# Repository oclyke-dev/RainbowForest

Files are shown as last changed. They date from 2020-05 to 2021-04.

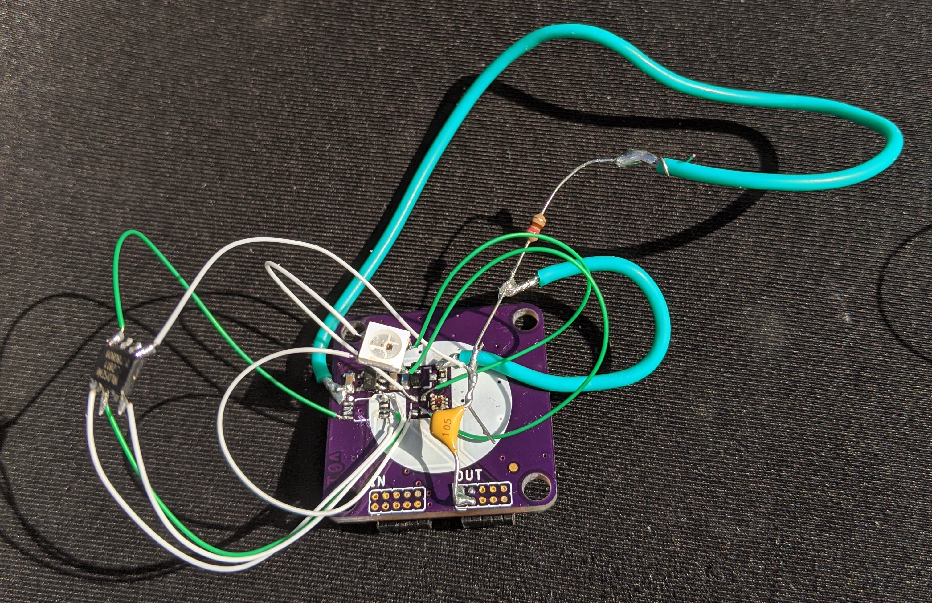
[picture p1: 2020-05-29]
process_documentation/v01_testing/Prototype v01_edited.jpg

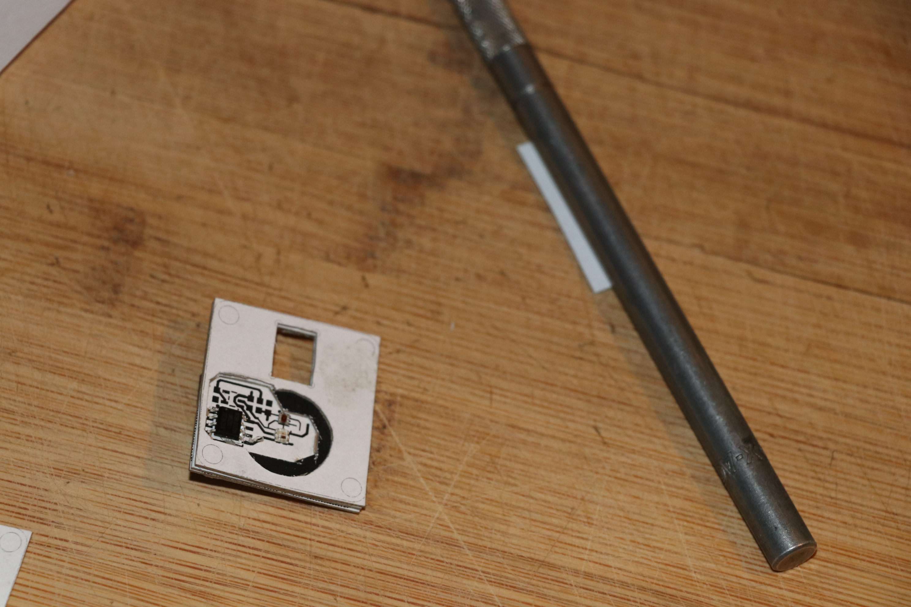
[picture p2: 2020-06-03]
process_documentation/IMG_0715.JPG

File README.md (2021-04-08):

# Rainbow Forest

Rainbow Forest is an interactive experience to compose short songs on a larger-than-life musical staff. Designed for the Museum of Boulder's 2020 Plazeum 2.0 exhibit this installation engages creativity and interaction through the combination of sounds and sights.

## Firmware

There are several microcontrollers working in concert (pun intended) to make the Rainbow Forest function. They are:

- **conductor** : the main processor conducting audio operations and the overall system operation
- **network hub** : the network hub handles communication between the column controllers and the conductor 
- **column controllers** : each column of notes on the staff is managed by an individual controller

The programs that run on each of these devices can be found in ```firmware/main```

Components that are common between programs can be found in ```firmware/components```. These components are expected to be symbolically linked into the main program directories. Arduino requires additional source code to be placed within a ```src``` directory. From the repository root directory one may run the link scripts to quickly make symbolic links from every component to every main program. 

- **linux**: ```./scripts/link.sh```
- **windows**: ```scripts\link.bat```

You may also create the symbolic links manually (Linux / Windows examples follow).

- **linux**: ```ln -s firmware/components/${component} firmware/main/${program}/src/components```
- **windows**: ```mklink /J firmware\main\%program%\src\components\%component% firmware\components\%component%```

Partial / experimental programs may be contained in ```firmware/prototyping``` for reference

## Hardware

The hardware directory contains the Eagle design files and Gerber manufacturing files for the original Rainbow Forest installation.

## Web

The Rainbow Forest installation connects to the world wide web, allowing users to check in on its status from anywhere.

In the museum a single-board computer running Chromium is used as a dedicated user interface.

```
./Chromium.app/Contents/MacOS/Chromium --app=https://oclyke.dev/rainbow-forest
```

## raspberry pi
the rainbow forest uses a local raspberry pi microcomputer to provide a user interface for museum visitors. this is acheived by using Chromium in kiosk mode. the raspberry pi also translates ```ws://``` messages into ```wss://``` messages for transfer to the main server (since the esp32s were unhappy running ```wss://```) 

[headless raspberry pi configuration](https://desertbot.io/blog/headless-raspberry-pi-3-bplus-ssh-wifi-setup)
[configuring rapberry pi for kiosk mode](https://die-antwort.eu/techblog/2017-12-setup-raspberry-pi-for-kiosk-mode/)
[using systemd on the pi](https://www.raspberrypi.org/documentation/linux/usage/systemd.md)
[using node and pm2 to daemonize applications](https://dev.to/bogdaaamn/run-your-nodejs-application-on-a-headless-raspberry-pi-4jnn)
[distributions of node for raspberry pi](https://github.com/nodesource/distributions)

## License

This project is subject to the license listed in file ```LICENSE.md```

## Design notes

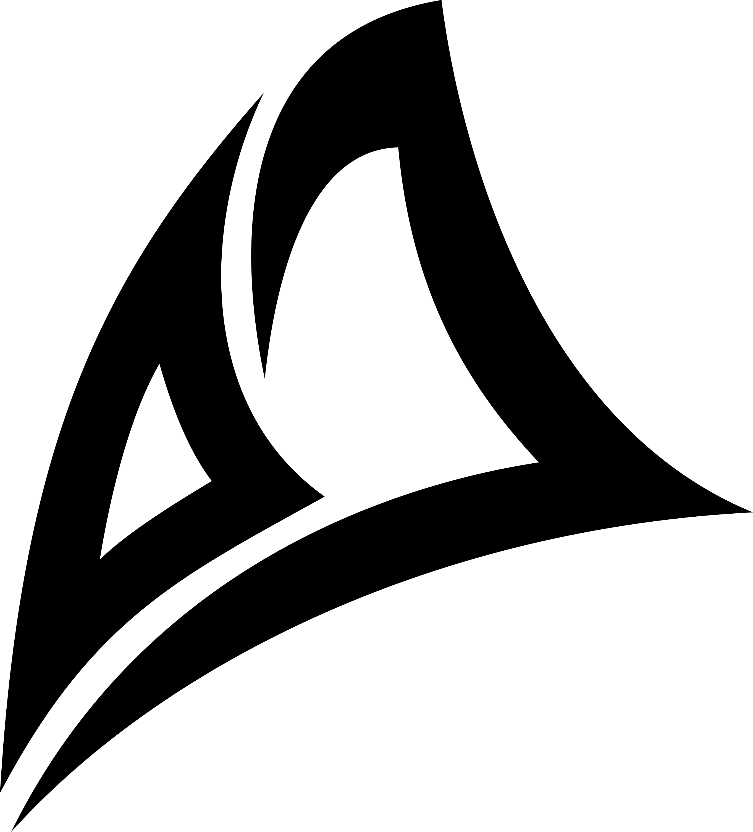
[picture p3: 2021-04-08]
web/client/src/assets/ocl_L.PNG

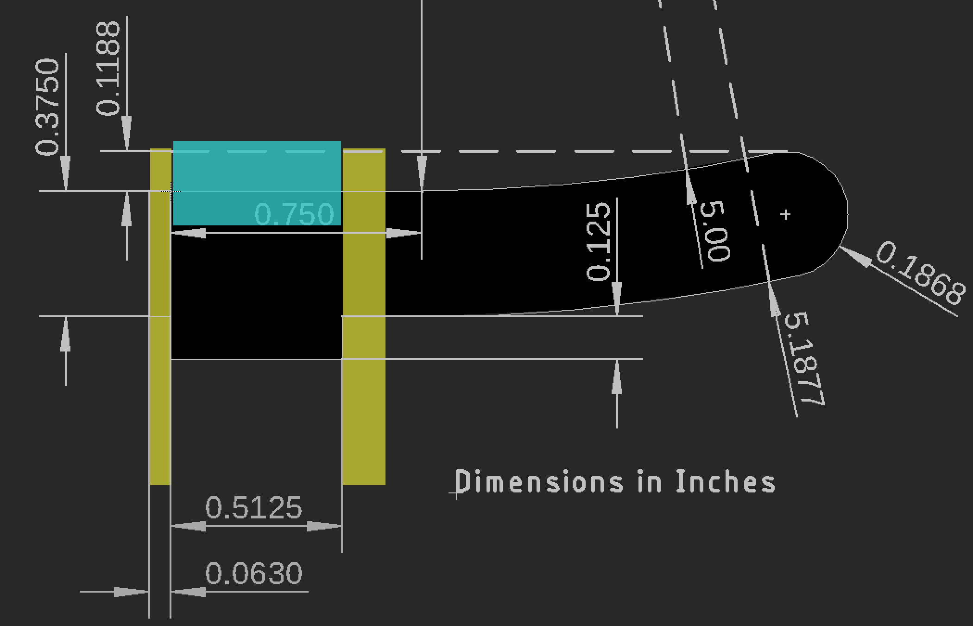
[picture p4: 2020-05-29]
process_documentation/Screen Shot 2020-04-22 at 11.09.29 PM.png

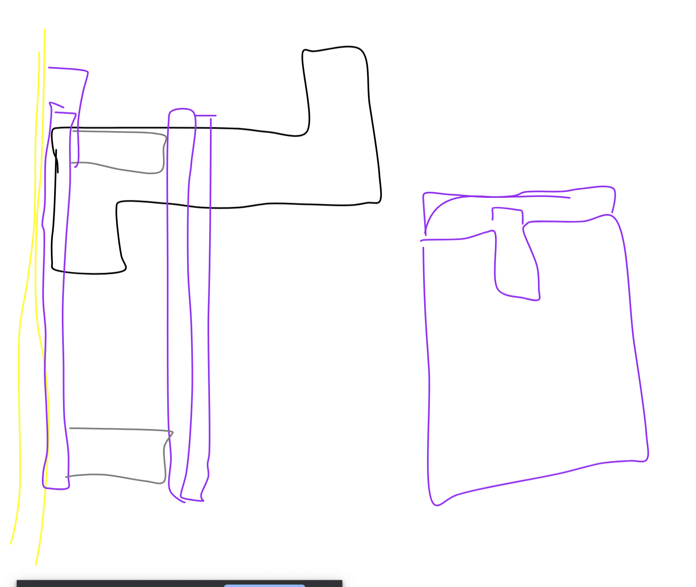
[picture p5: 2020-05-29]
process_documentation/Screen Shot 2020-04-22 at 2.52.55 PM.png

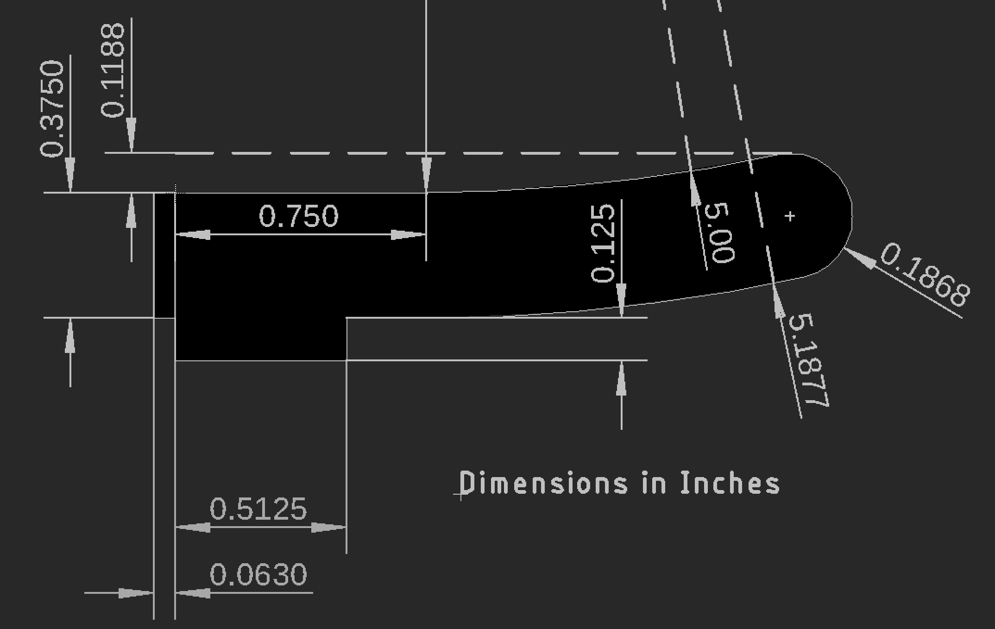
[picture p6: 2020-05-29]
process_documentation/Screen Shot 2020-04-22 at 11.09.07 PM.png

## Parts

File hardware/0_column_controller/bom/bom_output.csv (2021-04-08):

Qty | PROD_ID | Names | Value | Package
4 | CAP-00810 | C1; C2; C10; C11 | 0.1uF | 0603
5 | CAP-13930 | C3; C4; C7; C8; C9 | 1.0uF | 0603
2 | CAP-14106 | C5; C6 | 4.7uF | 0603
5 | DIO-08575 | D1; D5; D6; D7; D8 |  | LED-0603
2 | DIO-14072 | D2; D3 | 3A/10V/280mV | SOD-323
1 | DIO-00819 | D4 |  | LED-0603
1 | CONN-14485 | J1 |  | SCREWTERMINAL-3.5MM-4
1 | CONN-14122 | J3 |  | USB-C-16P
1 | CONN-14503 | J4 | JTAG | 2X5-SMD-1.27MM
1 | TRANS-13337 | Q1 |  | SC70-6
3 | RES-00824 | R1; R5; R6 | 10k | 0603
9 | RES-07856 | R2; R3; R4; R8; R9; R12; R13; R14; R15 | 1k | 0603
1 | RES-12581 | R7 | 10 | 0603
2 | RES-12083 | R10; R11 | 5.1k | 0603
2 | SWCH-13065 | S1; S2 |  | TACTILE_SWITCH_SMD_4.6X2.8MM
1 |  | U1 | ESP-WROVER-32ESP-WROVER-32 | ESP-WROVER-32
1 | VREG-12457 | U2 | 3.3V | SOT23-5
1 | IC-14020 | U3 | CP2102N | QFN24

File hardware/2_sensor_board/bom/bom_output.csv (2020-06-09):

Qty | PROD_ID | Names | Value | Package
3 | CAP-00868 | C1; C2; C3 | 1.0uF | 0603
1 |  | D1 | WS2812B | WS2812-2020
2 | CONN-14503 | J1; J2 | JTAG | 2X5-SMD-1.27MM
1 | RES-07861 | R2 | 220 | 0603
1 | IC-12055 | U1 | ISL29125 | ODFN-6
1 | VREG-12457 | U2 | 3.3V | SOT23-5
1 |  | U3 | WS2811 | SOIC-8

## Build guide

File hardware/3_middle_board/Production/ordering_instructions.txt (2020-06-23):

panel size, 99x100mm
PCB thickness, 1.6mm
number of layers, 2
soldermask color, Unknown
silkscreen color, White
oz copper, 1oz
finish, HASL lead free
stencils, bottom
pcs per panel, 9
min trace width, 10.0000mm / 0.3937in
min drill size, 1.2700mm / 0.0500in

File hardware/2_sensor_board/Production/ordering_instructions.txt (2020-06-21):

panel size, 99x100mm
PCB thickness, 1.6mm
number of layers, 2
soldermask color, Unknown
silkscreen color, White
oz copper, 1oz
finish, HASL lead free
stencils, top+bottom
pcs per panel, 9
min trace width, 0.2032mm / 0.0080in
min drill size, 0.3810mm / 0.0150in

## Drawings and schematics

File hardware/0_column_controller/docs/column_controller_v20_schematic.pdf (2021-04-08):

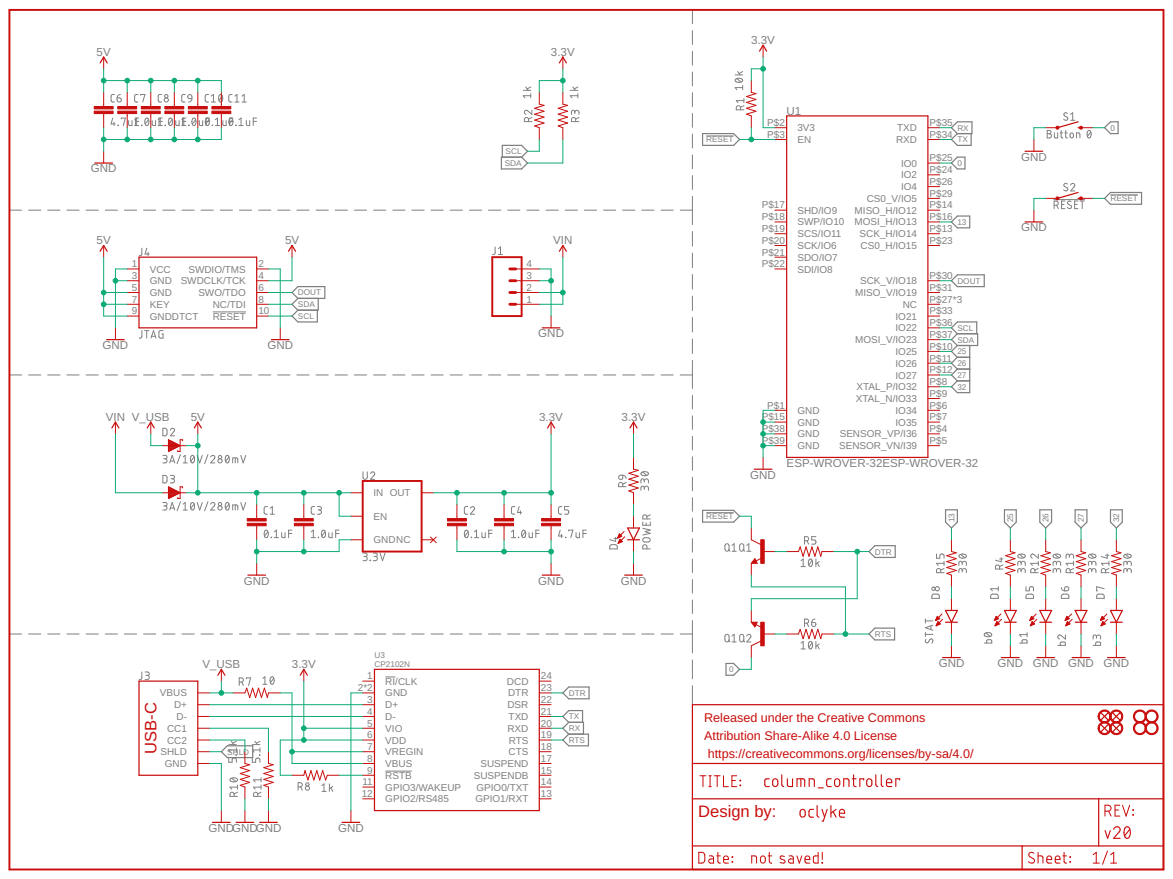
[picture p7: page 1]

Released under the Creative Commons Attribution Share-Alike 4.0 License

https://creativecommons.org/licenses/by-sa/4.0/

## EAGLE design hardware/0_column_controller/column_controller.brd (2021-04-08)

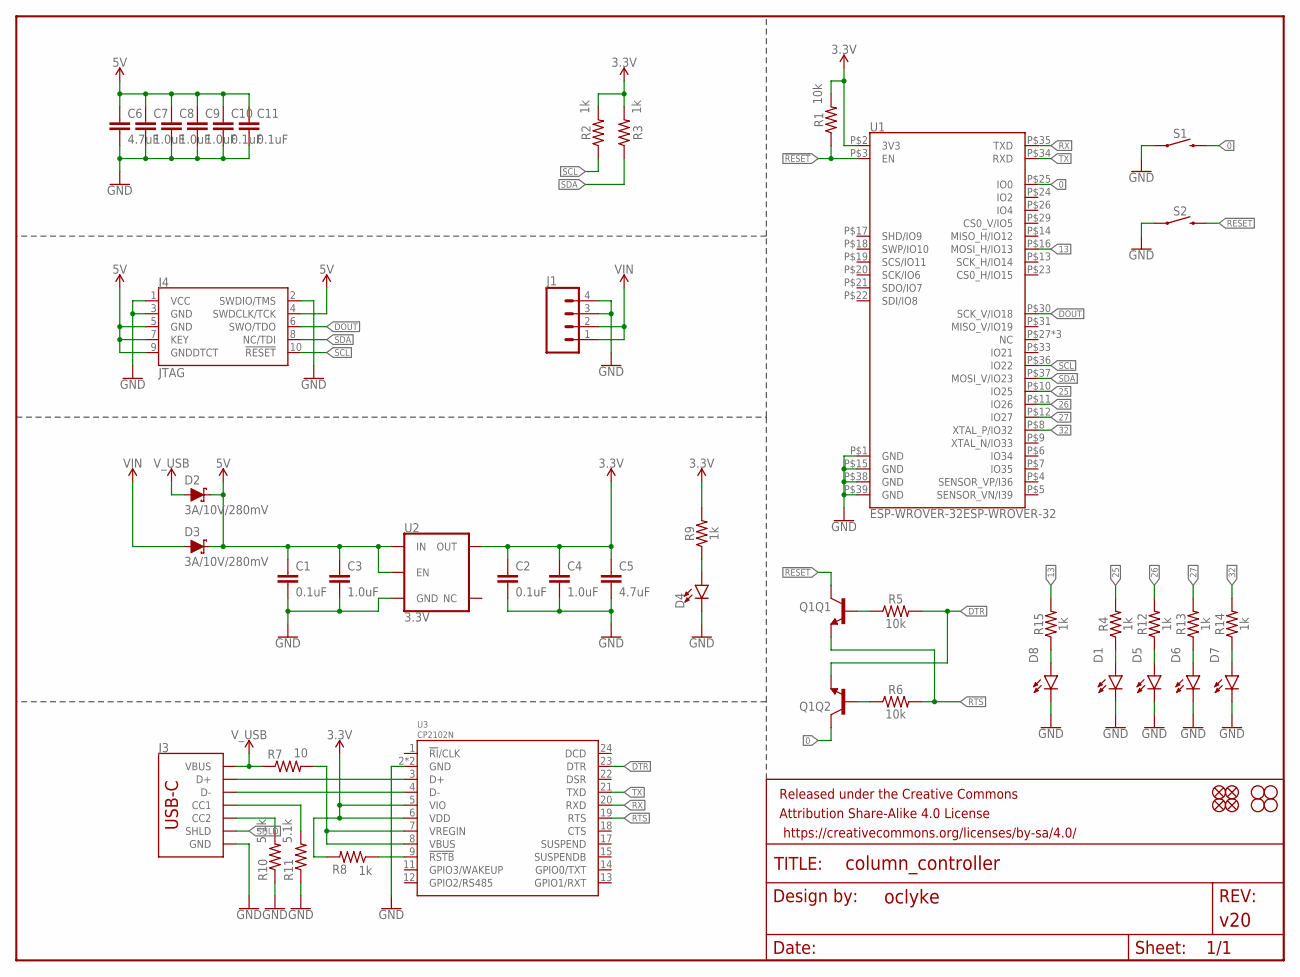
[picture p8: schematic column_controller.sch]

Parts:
C1, C2, C10, C11: 0.1uF; 0603
C3, C4, C7, C8, C9: 1.0uF; 0603
C5, C6: 4.7uF; 0603
D1, D5, D6, D7, D8: LED-BLUE0603; LED-0603
D2, D3: 3A/10V/280mV; SOD-323
D4: LED-RED0603; LED-0603
FD1, FD2, FD3, FD4: FIDUCIAL1X2; FIDUCIAL-1X2
FRAME1: FRAME-LETTER; CREATIVE_COMMONS
H1, H2, H3, H4: STAND-OFF#8; STAND-OFF-#8
J1: CONN_04SCREW; SCREWTERMINAL-3.5MM-4
J3: USB_C_2-LAYER; USB-C-16P
J4: JTAG; 2X5-SMD-1.27MM
Q1: TRANS_NPN_DUAL-MBT3904DW1T1; SC70-6
R1, R5, R6: 10k; 0603
R2, R3, R4, R8, R9, R12, R13, R14, R15: 1k; 0603
R7: 10; 0603
R10, R11: 5.1k; 0603
S1, S2: MOMENTARY-SWITCH-SPST-SMD-4.6X2.8MM; TACTILE_SWITCH_SMD_4.6X2.8MM
U1: ESP-WROVER-32ESP-WROVER-32; ESP-WROVER-32
U2: 3.3V; SOT23-5
U3: CP2102N; QFN24

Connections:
0: Q1.6 (C), S1.3 (2), S1.4 (2), U1.P$25 (IO0)
3.3V: C2.1, C4.1, C5.1, R1.2, R2.2, R3.2, R8.2, R9.2, U1.P$2 (3V3), U2.5 (OUT), U3.5 (VIO), U3.6 (VDD)
5V: C1.1, C3.1, C6.1, C7.1, C8.1, C9.1, C10.1, C11.1, D2.C, D3.C, J4.4 (SWDCLK/TCK), J4.5 (GND), J4.7 (KEY), J4.9 (GNDDTCT), U2.1 (IN), U2.3 (EN)
13: R15.2, U1.P$16 (MOSI_H/IO13)
25: R4.2, U1.P$10 (IO25)
26: R12.2, U1.P$11 (IO26)
27: R13.2, U1.P$12 (IO27)
32: R14.2, U1.P$8 (XTAL_P/IO32)
!RESET: Q1.3 (C), R1.1, S2.3 (2), S2.4 (2), U1.P$3 (EN)
DOUT: J4.6 (SWO/TDO), U1.P$30 (SCK_V/IO18)
DTR: Q1.1 (E), R5.2, U3.23 (DTR)
GND: C1.2, C2.2, C3.2, C4.2, C5.2, C6.2, C7.2, C8.2, C9.2, C10.2, C11.2, D1.C, D4.C, D5.C, D6.C, D7.C, D8.C, J1.3, J1.4, J3.GND, J3.GND2 (GND), J4.1 (VCC), J4.2 (SWDIO/TMS), J4.3 (GND), R10.1, R11.1, S1.1, S1.2 (1), S2.1, S2.2 (1), U1.P$1 (GND), U1.P$15 (GND), U1.P$38 (GND), U1.P$39 (GND), U2.2 (GND), U3.2 (GND), U3.PAD (GND)
unnamed: J3.A7 (D-), J3.B7 (D-), U3.4 (D-)
unnamed: J3.A6 (D+), J3.B6 (D+), U3.3 (D+)
unnamed: Q1.2 (B), R6.1
unnamed: D1.A, R4.1
unnamed: Q1.5 (B), R5.1
unnamed: R7.2, U3.7 (VREGIN), U3.8 (VBUS)
unnamed: R8.1, U3.9 (!RSTB)
unnamed: D4.A, R9.1
unnamed: D5.A, R12.1
unnamed: J3.A5 (CC1), R11.2
unnamed: J3.B5 (CC2), R10.2
unnamed: D6.A, R13.1
unnamed: D7.A, R14.1
unnamed: D8.A, R15.1
RTS: Q1.4 (E), R6.2, U3.19 (RTS)
RX: U1.P$35 (TXD), U3.20 (RXD)
SCL: J4.10 (!RESET), R2.1, U1.P$36 (IO22)
SDA: J4.8 (NC/TDI), R3.1, U1.P$37 (MOSI_V/IO23)
SHLD: J3.SHLD1 (SHLD), J3.SHLD2 (SHLD), J3.SHLD3 (SHLD), J3.SHLD4 (SHLD), J3.SHLD5 (SHLD), J3.SHLD6 (SHLD), J3.SHLD7 (SHLD), J3.SHLD8 (SHLD)
TX: U1.P$34 (RXD), U3.21 (TXD)
VIN: D3.A, J1.1, J1.2
V_USB: D2.A, J3.VBUS1 (VBUS), J3.VBUS2 (VBUS), R7.1

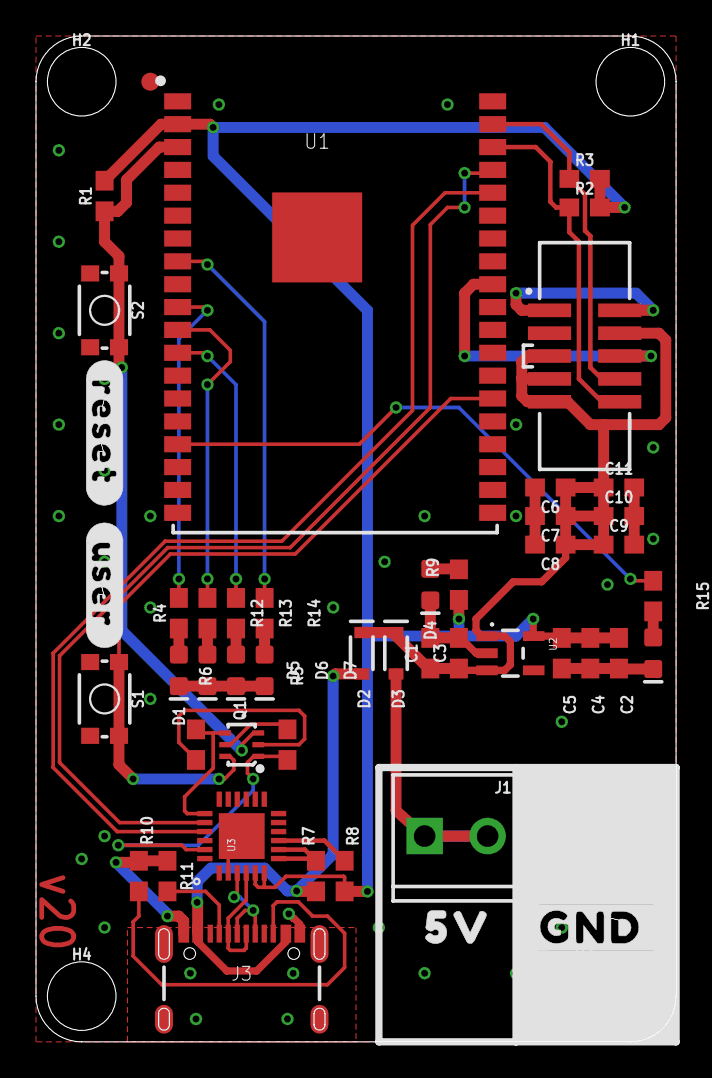
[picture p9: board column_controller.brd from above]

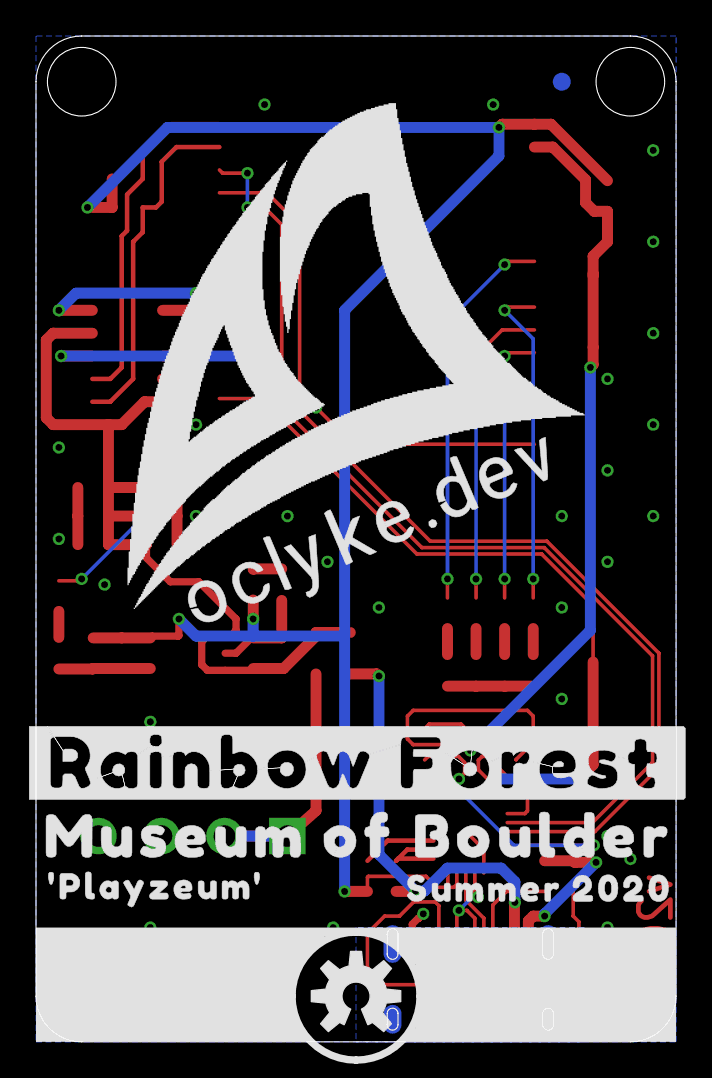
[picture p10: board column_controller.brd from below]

Board: 2 copper layers, 35.5 x 55.9 mm, 63 parts (9 on the bottom side), 34 nets.

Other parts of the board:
U$1: 5V2
U$2: #GND#6
U$4: #USER#2
U$5: #RESET#3
U$6: OCL_L#PNG
U$7: MUSEUM_OF_BOULDER9
U$8: OCLYKE#DEV7
U$9: #RAINBOW_FOREST#8
U$10: SUMMER_202010
U$11: #PLAYZEUM#10
U$12: OSHW-LOGO-M

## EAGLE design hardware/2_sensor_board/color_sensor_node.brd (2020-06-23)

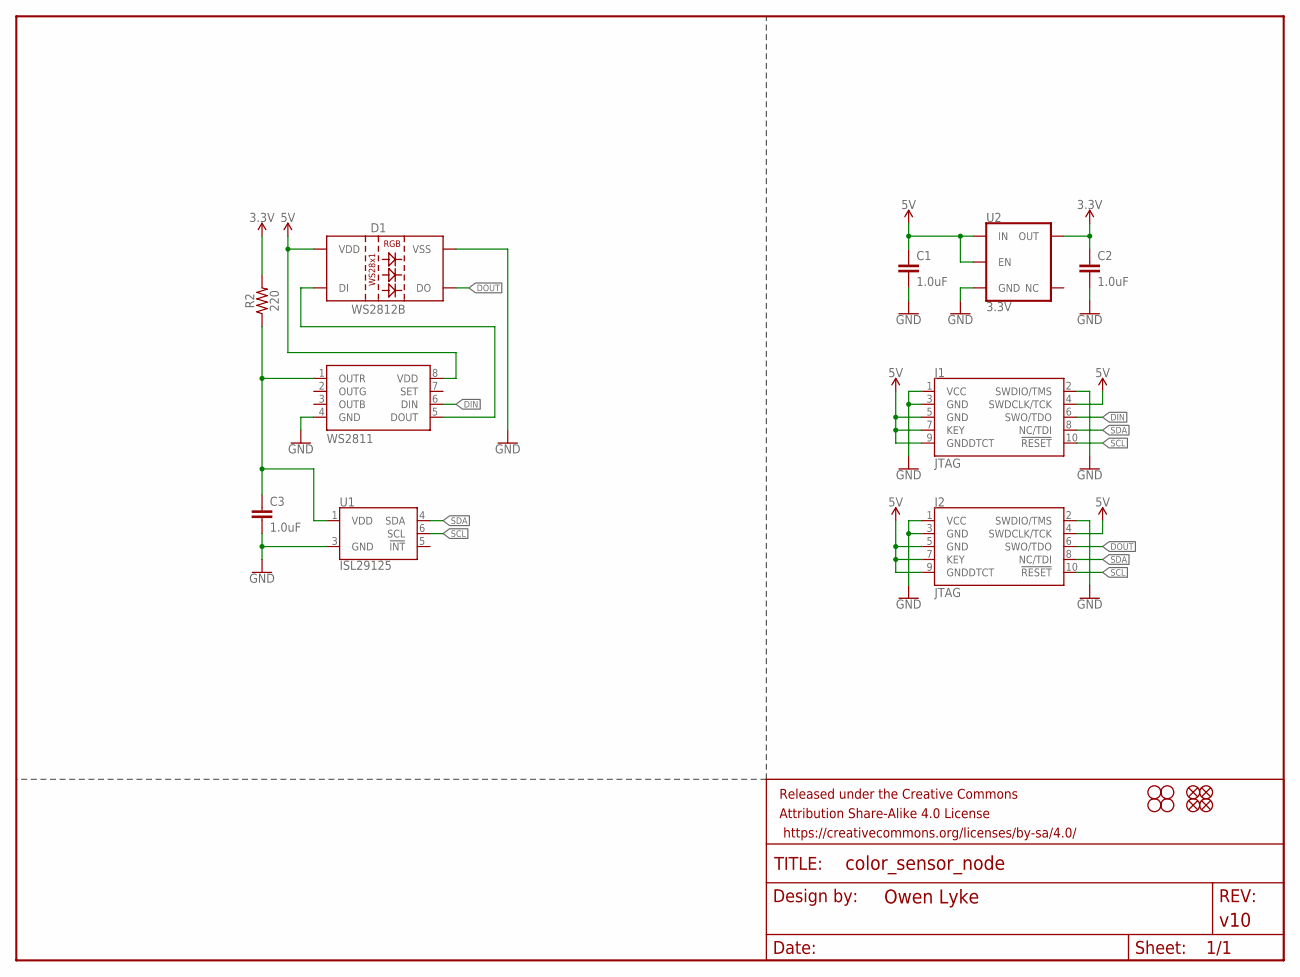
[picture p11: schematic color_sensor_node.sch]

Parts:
C1, C2, C3: 1.0uF; 0603
D1: WS2812B; WS2812-2020
FD1, FD2, FD3, FD4: FIDUCIAL1X2; FIDUCIAL-1X2
FRAME1: FRAME-LETTER; CREATIVE_COMMONS
H1, H2, H3, H4: STAND-OFF#8; STAND-OFF-#8
J1, J2: JTAG; 2X5-SMD-1.27MM
R2: 220; 0603
U1: ISL29125; ODFN-6
U2: 3.3V; SOT23-5
U3: WS2811; SOIC-8

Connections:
3.3V: C2.1, R2.2, U2.5 (OUT)
5V: C1.1, D1.4 (VDD), J1.4 (SWDCLK/TCK), J1.5 (GND), J1.7 (KEY), J1.9 (GNDDTCT), J2.4 (SWDCLK/TCK), J2.5 (GND), J2.7 (KEY), J2.9 (GNDDTCT), U2.1 (IN), U2.3 (EN), U3.8 (VDD)
DIN: J1.6 (SWO/TDO), U3.6 (DIN)
DOUT: D1.1 (DO), J2.6 (SWO/TDO)
GND: C1.2, C2.2, C3.2, D1.2 (VSS), J1.1 (VCC), J1.2 (SWDIO/TMS), J1.3 (GND), J2.1 (VCC), J2.2 (SWDIO/TMS), J2.3 (GND), U1.3 (GND), U2.2 (GND), U3.4 (GND)
unnamed: C3.1, R2.1, U1.1 (VDD), U3.1 (OUTR)
unnamed: D1.3 (DI), U3.5 (DOUT)
SCL: J1.10 (!RESET), J2.10 (!RESET), U1.6 (SCL)
SDA: J1.8 (NC/TDI), J2.8 (NC/TDI), U1.4 (SDA)

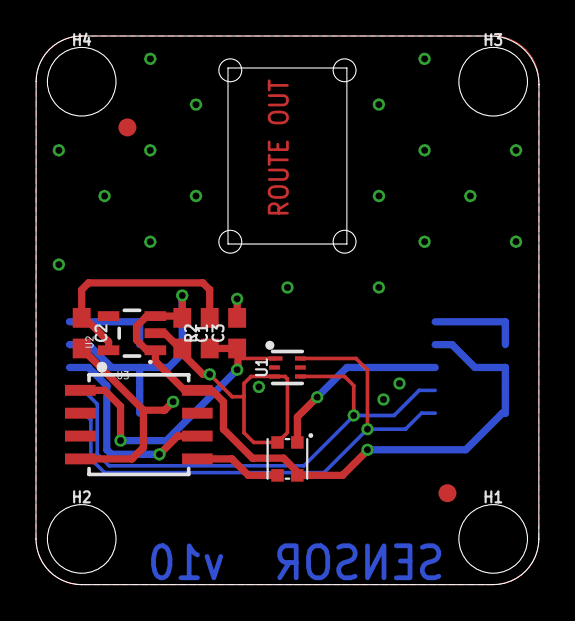
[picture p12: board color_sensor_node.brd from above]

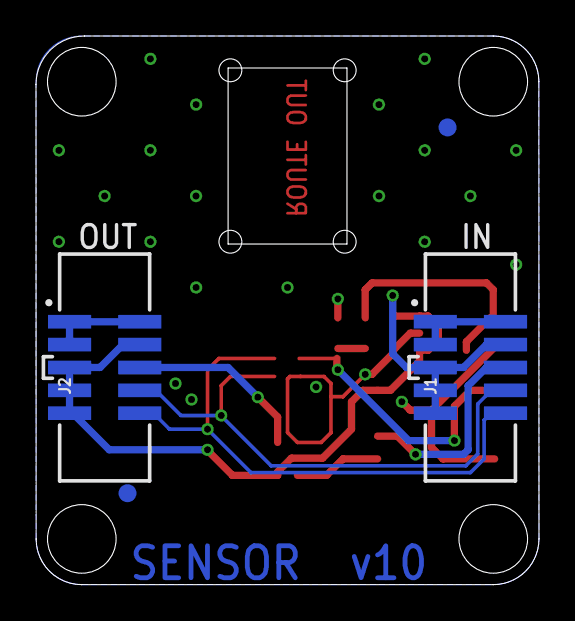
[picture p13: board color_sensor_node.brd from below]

Board: 2 copper layers, 27.9 x 30.5 mm, 19 parts (4 on the bottom side), 9 nets.

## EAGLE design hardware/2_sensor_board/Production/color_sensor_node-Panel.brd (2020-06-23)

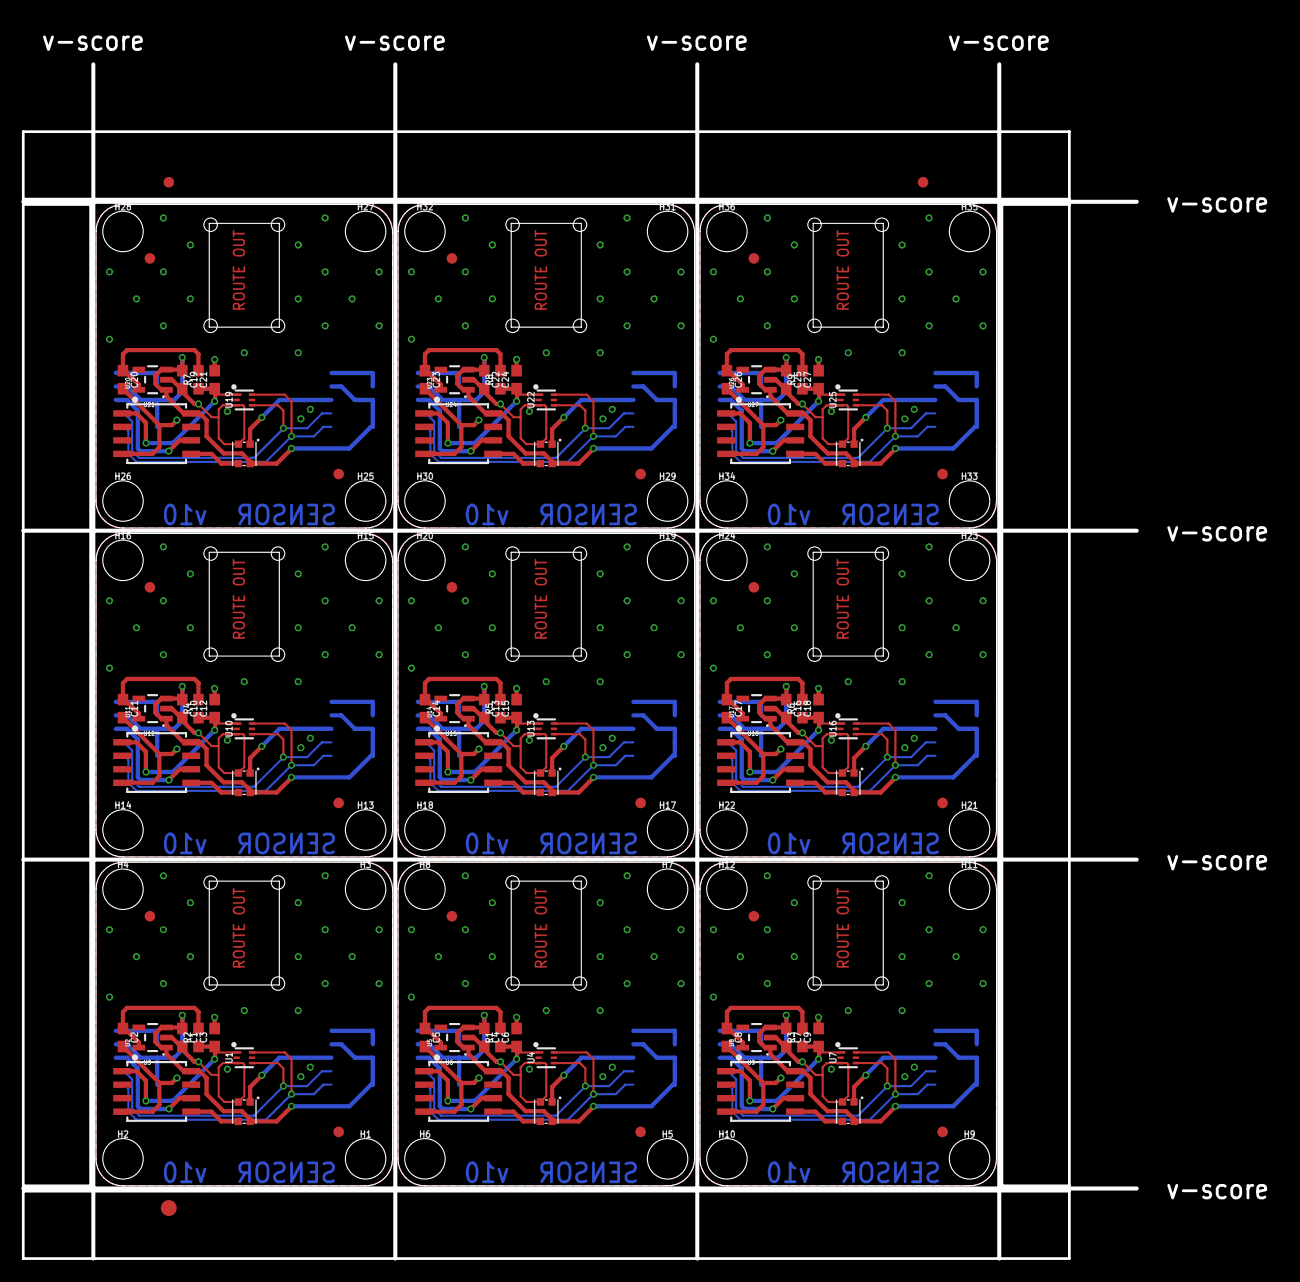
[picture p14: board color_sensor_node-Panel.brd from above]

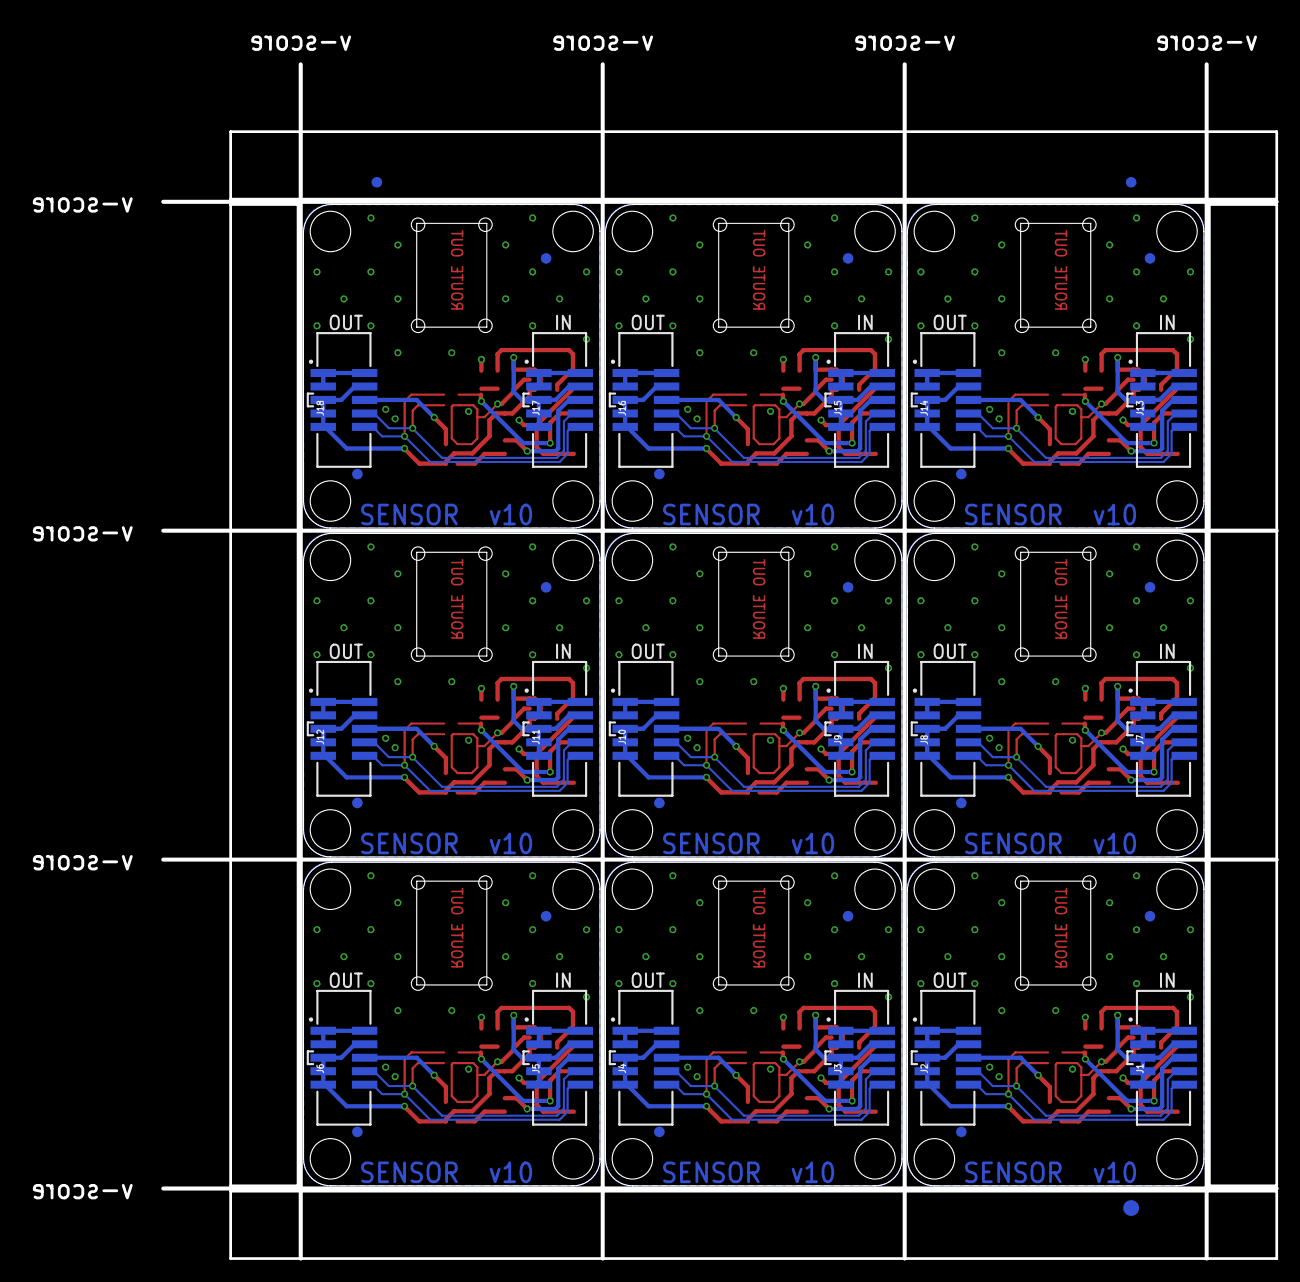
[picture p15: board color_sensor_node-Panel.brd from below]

Board: 2 copper layers, 104.9 x 112.5 mm, 168 parts (39 on the bottom side), 81 nets.

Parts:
C1, C2, C3, C4, C5, C6, C7, C8, C9, C10, C11, C12, C13, C14, C15, C16, C17, C18, C19, C20, C21, C22, C23, C24, C25, C26, C27: 1.0uF; 0603
D1, D2, D3, D4, D5, D6, D7, D8, D9: WS2812B; WS2812-2020
E$1, E$2, E$3, E$4: FIDUCIAL-1X2
E$5, E$6: FIDUCIAL-1.5X3
FD1, FD2, FD3, FD4, FD5, FD6, FD7, FD8, FD9, FD10, FD11, FD12, FD13, FD14, FD15, FD16, FD17, FD18, FD19, FD20, FD21, FD22, FD23, FD24, FD25, FD26, FD27, FD28, FD29, FD30, FD31, FD32, FD33, FD34, FD35, FD36: FIDUCIAL1X2; FIDUCIAL-1X2
H1, H2, H3, H4, H5, H6, H7, H8, H9, H10, H11, H12, H13, H14, H15, H16, H17, H18, H19, H20, H21, H22, H23, H24, H25, H26, H27, H28, H29, H30, H31, H32, H33, H34, H35, H36: STAND-OFF#8; STAND-OFF-#8
J1, J2, J3, J4, J5, J6, J7, J8, J9, J10, J11, J12, J13, J14, J15, J16, J17, J18: JTAG; 2X5-SMD-1.27MM
R1, R2, R3, R4, R5, R6, R7, R8, R9: 220; 0603
U1, U4, U7, U10, U13, U16, U19, U22, U25: ISL29125; ODFN-6
U2, U5, U8, U11, U14, U17, U20, U23, U26: 3.3V; SOT23-5
U3, U6, U9, U12, U15, U18, U21, U24, U27: WS2811; SOIC-8

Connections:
3.3V: C2.1, R2.2, U2.5
3.3V1: C5.1, R1.2, U5.5
3.3V2: C8.1, R3.2, U8.5
3.3V3: C11.1, R4.2, U11.5
3.3V4: C14.1, R5.2, U14.5
3.3V5: C17.1, R6.2, U17.5
3.3V6: C20.1, R7.2, U20.5
3.3V7: C23.1, R8.2, U23.5
3.3V8: C26.1, R9.2, U26.5
5V: C1.1, D1.4, J1.4, J1.5, J1.7, J1.9, J2.4, J2.5, J2.7, J2.9, U2.1, U2.3, U3.8
5V1: C4.1, D2.4, J3.4, J3.5, J3.7, J3.9, J4.4, J4.5, J4.7, J4.9, U5.1, U5.3, U6.8
5V2: C7.1, D3.4, J5.4, J5.5, J5.7, J5.9, J6.4, J6.5, J6.7, J6.9, U8.1, U8.3, U9.8
5V3: C10.1, D4.4, J7.4, J7.5, J7.7, J7.9, J8.4, J8.5, J8.7, J8.9, U11.1, U11.3, U12.8
5V4: C13.1, D5.4, J9.4, J9.5, J9.7, J9.9, J10.4, J10.5, J10.7, J10.9, U14.1, U14.3, U15.8
5V5: C16.1, D6.4, J11.4, J11.5, J11.7, J11.9, J12.4, J12.5, J12.7, J12.9, U17.1, U17.3, U18.8
5V6: C19.1, D7.4, J13.4, J13.5, J13.7, J13.9, J14.4, J14.5, J14.7, J14.9, U20.1, U20.3, U21.8
5V7: C22.1, D8.4, J15.4, J15.5, J15.7, J15.9, J16.4, J16.5, J16.7, J16.9, U23.1, U23.3, U24.8
5V8: C25.1, D9.4, J17.4, J17.5, J17.7, J17.9, J18.4, J18.5, J18.7, J18.9, U26.1, U26.3, U27.8
DIN: J1.6, U3.6
DIN1: J3.6, U6.6
DIN2: J5.6, U9.6
DIN3: J7.6, U12.6
DIN4: J9.6, U15.6
DIN5: J11.6, U18.6
DIN6: J13.6, U21.6
DIN7: J15.6, U24.6
DIN8: J17.6, U27.6
DOUT: D1.1, J2.6
DOUT1: D2.1, J4.6
DOUT2: D3.1, J6.6
DOUT3: D4.1, J8.6
DOUT4: D5.1, J10.6
DOUT5: D6.1, J12.6
DOUT6: D7.1, J14.6
DOUT7: D8.1, J16.6
DOUT8: D9.1, J18.6
GND: C1.2, C2.2, C3.2, D1.2, J1.1, J1.2, J1.3, J2.1, J2.2, J2.3, U1.3, U2.2, U3.4
GND1: C4.2, C5.2, C6.2, D2.2, J3.1, J3.2, J3.3, J4.1, J4.2, J4.3, U4.3, U5.2, U6.4
GND2: C7.2, C8.2, C9.2, D3.2, J5.1, J5.2, J5.3, J6.1, J6.2, J6.3, U7.3, U8.2, U9.4
GND3: C10.2, C11.2, C12.2, D4.2, J7.1, J7.2, J7.3, J8.1, J8.2, J8.3, U10.3, U11.2, U12.4
GND4: C13.2, C14.2, C15.2, D5.2, J9.1, J9.2, J9.3, J10.1, J10.2, J10.3, U13.3, U14.2, U15.4
GND5: C16.2, C17.2, C18.2, D6.2, J11.1, J11.2, J11.3, J12.1, J12.2, J12.3, U16.3, U17.2, U18.4
GND6: C19.2, C20.2, C21.2, D7.2, J13.1, J13.2, J13.3, J14.1, J14.2, J14.3, U19.3, U20.2, U21.4
GND7: C22.2, C23.2, C24.2, D8.2, J15.1, J15.2, J15.3, J16.1, J16.2, J16.3, U22.3, U23.2, U24.4
GND8: C25.2, C26.2, C27.2, D9.2, J17.1, J17.2, J17.3, J18.1, J18.2, J18.3, U25.3, U26.2, U27.4
unnamed: D2.3, U6.5
unnamed: C3.1, R2.1, U1.1, U3.1
unnamed: C6.1, R1.1, U4.1, U6.1
unnamed: D1.3, U3.5
unnamed: D3.3, U9.5
unnamed: C9.1, R3.1, U7.1, U9.1
unnamed: D4.3, U12.5
unnamed: C12.1, R4.1, U10.1, U12.1
unnamed: D5.3, U15.5
unnamed: C15.1, R5.1, U13.1, U15.1
unnamed: D6.3, U18.5
unnamed: C18.1, R6.1, U16.1, U18.1
unnamed: D7.3, U21.5
unnamed: C21.1, R7.1, U19.1, U21.1
unnamed: D8.3, U24.5
unnamed: C24.1, R8.1, U22.1, U24.1
unnamed: D9.3, U27.5
unnamed: C27.1, R9.1, U25.1, U27.1
SCL: J1.10, J2.10, U1.6
SCL1: J3.10, J4.10, U4.6
SCL2: J5.10, J6.10, U7.6
SCL3: J7.10, J8.10, U10.6
SCL4: J9.10, J10.10, U13.6
SCL5: J11.10, J12.10, U16.6
SCL6: J13.10, J14.10, U19.6
SCL7: J15.10, J16.10, U22.6
SCL8: J17.10, J18.10, U25.6
SDA: J1.8, J2.8, U1.4
SDA1: J3.8, J4.8, U4.4
SDA2: J5.8, J6.8, U7.4
SDA3: J7.8, J8.8, U10.4
SDA4: J9.8, J10.8, U13.4
SDA5: J11.8, J12.8, U16.4
SDA6: J13.8, J14.8, U19.4
SDA7: J15.8, J16.8, U22.4
SDA8: J17.8, J18.8, U25.4

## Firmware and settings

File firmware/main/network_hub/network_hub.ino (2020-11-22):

/* 
// This file is subject to the terms and conditions defined in
// file 'LICENSE.md', which is part of this source code package.
*/

// BOARD: SparkFun SAMD21 Mini Breakout

#include "src/components/configuration/configuration.h"
#include "src/components/uart_bridge/uart_bridge.h"
#include "src/components/staff/staff.h"
#include "src/components/cart/cart.h"
#include "src/components/cat/cat.h"
#include "src/components/cmt/cmt.h"

#include <Wire.h>
#include "wiring_private.h" // pinPeripheral() function

#define LED0 A0
#define LED1 A3
#define LED2 8
#define LED3 9

#define BUTTON0 10
#define BUTTON1 12

#define RAND_PIN A1

#define DEBUG_PORT SerialUSB
#define DEBUG_BAUD (115200)

#define BRIDGE_PORT Serial1
#define BRIDGE_BAUD (115200)
UARTBridge <cart_t> cartBridge(BRIDGE_PORT);
UARTBridge <cat_t> catBridge(BRIDGE_PORT);
cart_t cart;
cat_t cat;
Staff <staff_data_t> staff;

#define NETWORK_SDA_PIN 11
#define NETWORK_SCL_PIN 13
#define NETWORK_WIRE_IT_HANDLER SERCOM1_Handler
TwoWire NetworkWire(&sercom1, NETWORK_SDA_PIN, NETWORK_SCL_PIN);
#define NETWORK_ADDRESS_BY_COL(c) (c + 0x04)

volatile bool cat_received = false;
volatile bool cleanup_cat_received = false;
volatile bool full_update_requested = true;
bool full_update_sent = false;

volatile bool button0 = false;
void button0ISR() {
  button0 = true;
}

volatile bool button1 = false;
void button1ISR() {
  button0 = true;
}

void onCatReception(cat_t* cat, void* args){
  cat_received = true;

  if(cat->col >= STAFF_COLS){
    DEBUG_PORT.println("received an invalid cat");
    return;
  }

  size_t node_data_size = (sizeof(column_map_t)/sizeof(uint8_t)); // note: if node_data_size * STAFF_ROWS > 32 you will need to use separate transmissions!
  uint8_t r = ((cat->rH) << 4) | ((cat->rL) & 0x0F);              // reconstructed red component of color
  uint8_t g = ((cat->gH) << 4) | ((cat->gL) & 0x0F);              // reconstructed green component of color
  uint8_t b = ((cat->bH) << 4) | ((cat->bL) & 0x0F);              // reconstructed blue component of color

  DEBUG_PORT.print("conductor --> column[");
  DEBUG_PORT.print(cat->col);
  DEBUG_PORT.print("]");
  DEBUG_PORT.print(", {");
  DEBUG_PORT.print(" col: ");
  DEBUG_PORT.print(cat->col);
  DEBUG_PORT.print(", row: ");
  DEBUG_PORT.print(cat->row);
  DEBUG_PORT.print(", r: ");
  DEBUG_PORT.print(r);
  DEBUG_PORT.print(", g: ");
  DEBUG_PORT.print(g);
  DEBUG_PORT.print(", b: ");
  DEBUG_PORT.print(b);
  DEBUG_PORT.print(" }");
  DEBUG_PORT.println();

  if(cat->row == COMMAND_REQ_FULL_UPDATE){
    DEBUG_PORT.println("Full Update Requested!");
    full_update_requested = true;
    return;
  }

  if(cat->row == COMMAND_SET_COLUMN_COLOR){
    DEBUG_PORT.println("Column Color Set Requested!");
    NetworkWire.beginTransmission(NETWORK_ADDRESS_BY_COL(cat->col));
    NetworkWire.write(0);                                             // begin at register 0
    for(size_t node_idx = 0; node_idx < STAFF_ROWS; node_idx++){
      NetworkWire.write(0x00);                                        // dummy write to the read-only value reg
      NetworkWire.write(r);                                           // write red
      NetworkWire.write(g);                                           // write green
      NetworkWire.write(b);                                           // write blue
    }
    NetworkWire.endTransmission();
    return;
  }

  if((cat->col < STAFF_COLS) && (cat->row < STAFF_ROWS)){
    DEBUG_PORT.println("Individual Color Set Requested!");
    NetworkWire.beginTransmission(NETWORK_ADDRESS_BY_COL(cat->col));
    NetworkWire.write(node_data_size * cat->row);                      // begin at proper offset for row
    NetworkWire.write(0x00);                                          // dummy write to the read-only value reg
    NetworkWire.write(r);                                             // write red
    NetworkWire.write(g);                                             // write green
    NetworkWire.write(b);                                             // write blue
    NetworkWire.endTransmission();
    return;
  }
  
  DEBUG_PORT.println("Unrecognized CAT...");
}

void setup() {
  DEBUG_PORT.begin(DEBUG_BAUD);
  BRIDGE_PORT.begin(BRIDGE_BAUD);

  pinMode(BUTTON0, INPUT_PULLUP);
  pinMode(BUTTON1, INPUT_PULLUP);
  attachInterrupt(BUTTON0, button0ISR, RISING);
  attachInterrupt(BUTTON1, button1ISR, RISING);

  pinMode(LED0, OUTPUT);
  pinMode(LED1, OUTPUT);
  pinMode(LED2, OUTPUT);
  pinMode(LED3, OUTPUT);

  digitalWrite(LED0, HIGH);
  digitalWrite(LED1, HIGH);
  digitalWrite(LED2, HIGH);
  digitalWrite(LED3, HIGH);

  delay(250);

  digitalWrite(LED0, LOW);
  digitalWrite(LED1, LOW);
  digitalWrite(LED2, LOW);
  digitalWrite(LED3, LOW);

  staff.setSize(STAFF_COLS, STAFF_ROWS);

  NetworkWire.begin();
  pinPeripheral(NETWORK_SDA_PIN, PIO_SERCOM);
  pinPeripheral(NETWORK_SCL_PIN, PIO_SERCOM);
  
  catBridge.onReceive(onCatReception, NULL);

  // prevent user input until setup is complete
  button0 = false;
  button1 = false;
}

void loop() {
  sampleColumns();

  catBridge.check();
  if(button0){
    DEBUG_PORT.println("button0 released");
    button0 = false;
  }

  if(cat_received){
    digitalWrite(LED1, HIGH);
    cat_received = false;
    cleanup_cat_received = true;
  }
  if(cleanup_cat_received){
    cleanup_cat_received = false;
    digitalWrite(LED1, LOW);
  }

  // alive heartbeat
  static bool led0_val = false;
  digitalWrite(LED0, led0_val);
  led0_val = !led0_val;

  // static uint8_t col_to_set = 0;
  // if(DEBUG_PORT.available()){
  //   DEBUG_PORT.read();
  //   cat.row = COMMAND_SET_COLUMN_COLOR;
  //   cat.col = col_to_set;
  //   cat.rH = 0x00;
  //   cat.rL = 0x00;
  //   cat.bH = 0x00;
  //   cat.bL = 0x00;
  //   cat.gH = 0x00;
  //   cat.gL = 0x00;
  //   onCatReception(&cat, NULL);
  //   col_to_set++;
  //   if(col_to_set >= STAFF_COLS){
  //     col_to_set = 0;
  //   }
  // }

  // uint32_t now = millis();
  // static uint32_t debug_staff = 0;
  // if((now - debug_staff) > 100){
  //   debug_staff = now;
  //   debugShowStaff();
  // }
}

void sampleColumns( void ){
  size_t node_data_size = (sizeof(column_map_t)/sizeof(uint8_t));
  size_t bytes_per_column = node_data_size*STAFF_ROWS;                // note: if node_data_size * STAFF_ROWS > 32 you will need to use separate transmissions!
  staff_data_t prev = 0x00;

  full_update_sent = full_update_requested; // ensure that when a full update is requested at least one full cycle is captured
  
  bool success = true;

  // sample through all the positions, if there is a change send it as a cart message to the conductor
  for(size_t col = 0; col < STAFF_COLS; col++){
    NetworkWire.beginTransmission(NETWORK_ADDRESS_BY_COL(col));
    NetworkWire.write(0);
    NetworkWire.endTransmission(false);
    size_t bytes_received = NetworkWire.requestFrom(NETWORK_ADDRESS_BY_COL(col), bytes_per_column);
    if(bytes_received != bytes_per_column){
      while(NetworkWire.available()){ NetworkWire.read(); } // dump any straggler bytes
      success = false;
      DEBUG_PORT.print("error reading data from column: ");
      DEBUG_PORT.print(col);
      DEBUG_PORT.print(". time (ms): ");
      DEBUG_PORT.print(millis());
      DEBUG_PORT.println();
      continue;                                             // continue to the next column (big failure)
    }

    for(size_t row = 0; row < STAFF_ROWS; row++){
      staff_data_t current = NetworkWire.read();            // get the value for this row position
      NetworkWire.read(); // r  (read out the color bytes so that the next row's value is next in line)
      NetworkWire.read(); // g
      NetworkWire.read(); // b

      prev = staff[col][row];
      staff[col][row] = current;

//      if(1){ // temporary
       if((prev != current) || (full_update_requested)){     // send the current value if the value at this position has changed or a full update is requested
      
        cart.col = col;
        cart.row = row;
        cart.val = current;

        DEBUG_PORT.print("column[");
        DEBUG_PORT.print(cart.col);
        DEBUG_PORT.print("]");
        DEBUG_PORT.print(" --> conductor , {");
        DEBUG_PORT.print(" col: ");
        DEBUG_PORT.print(cart.col);
        DEBUG_PORT.print(", row: ");
        DEBUG_PORT.print(cart.row);
        DEBUG_PORT.print(", val: ");
        DEBUG_PORT.print(cart.val);
        DEBUG_PORT.print(" }");
        DEBUG_PORT.println();

        cartBridge.send(&cart);
      }
    }
  }

//  onCatReception(&cat, NULL); // use this to re-send the current cat (increased sends means more likely to remedy a failure)

  if(full_update_sent){
    full_update_sent = false;
    full_update_requested = false;
  }

  if(success){
    digitalWrite(LED3, HIGH);
  }else{
    digitalWrite(LED3, LOW);
  }
}



void debugShowStaff( void ){

  for(size_t idx = 0; idx < 100; idx++){
    DEBUG_PORT.println();
  }

  for(size_t r = STAFF_ROWS; r > 0; r--){
    size_t row = r-1;
    DEBUG_PORT.print("row [");
    DEBUG_PORT.print(row);
    DEBUG_PORT.print("]: ");
    for(size_t col = 0; col < STAFF_COLS; col++){
      DEBUG_PORT.print(staff[col][row]);
      DEBUG_PORT.print(", ");
    }
    DEBUG_PORT.println();
  }
}

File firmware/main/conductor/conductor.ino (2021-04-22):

/* 
// This file is subject to the terms and conditions defined in
// file 'LICENSE.md', which is part of this source code package.
*/

#include "tempo_dial.h"
#include "src/components/configuration/configuration.h"

#define DEBUG_PORT Serial
#define DEBUG_BAUD (115200)

#define REST_INACTIVE_SEC (60)
uint32_t rest_inactive = 0;
#define PAUSED_BLINK_PERIOD_MS (1000)

#define MAX_BPM (160)
#define MIN_BPM (60)
#define STEP_BPM (4)
#define DEF_BPM (80)
#define BPM2USPERIOD(B) (60000000/(B))

#define EXAMPLE1_PIN (2)
#define EXAMPLE2_PIN (3)
#define EXAMPLE3_PIN (4)
#define EXAMPLE4_PIN (5)
#define EXAMPLE5_PIN (6)
#define PLAYPAUSE_PIN (8)

IntervalTimer playbackTimer;
volatile bool playNext = false;
volatile bool playbackRunning = true;
volatile uint8_t playbackColumn = 0;

bool playButtonIllumination = true;

void setup() {
  DEBUG_PORT.begin(DEBUG_BAUD);

  input_setup();
  tempo_setup();
}

void loop() {
  static uint32_t prev_time = 0;
  uint32_t now = millis();

  if(!playbackRunning){
    static uint32_t toggle = 0;
    if(now >= toggle){
      toggle += (PAUSED_BLINK_PERIOD_MS/2);
      playButtonIllumination != playButtonIllumination;
      digitalWrite(PLAYPAUSE_PIN, playButtonIllumination);
      DEBUG_PORT.print("paused. time (ms): ");
      DEBUG_PORT.println(millis());
    }
  }

}

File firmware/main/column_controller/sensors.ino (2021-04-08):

/* 
// This file is subject to the terms and conditions defined in
// file 'LICENSE.md', which is part of this source code package.
*/

void read_idler( void ){
  FastLED.show(); // allow led updates while reading
}

void detect(SensorNode* node, size_t idx, void* args){
  node->read(read_idler);
  
  rgb_f_t rgb;
  rgb.r = rgbElemByUI16(node->getRed());
  rgb.g = rgbElemByUI16(node->getGreen());
  rgb.b = rgbElemByUI16(node->getBlue());

  // for normal operation detect colors based on sensor results
  size_t color_index;
  if(COLOR_DETECT_OK == detectedColor(&rgb, &color_index)){
    staff_data_t val = detectable_colors[color_index].staff_val;
    detection_ok_staff[0][idx] = true;
    staff[0][idx] = (staff_data_t)val;
  }else{
    detection_ok_staff[0][idx] = false;
  }

  delay(random(64)); // additional delay to enhance blinking randomness
}

void detect_fake(SensorNode* node, size_t idx, void* args){
  staff[0][idx] = random(0, STAFF_VALS + 1);
  detection_ok_staff[0][idx] = true;

  uint32_t now = millis();
  while((millis() - now) < 500){
    read_idler();
  }
  
  delay(random(64));
}

void printInfo(SensorNode* node, size_t idx, void* args){
  
  DEBUG_PORT.printf("%d: ", idx);

  staff_data_t current = staff[0][idx];
  if(detection_ok_staff[0][idx]){
    DEBUG_PORT.printf("%s", getColorNameByStaffValue(current));
  }else{
    DEBUG_PORT.printf("unknown");
  }

  DEBUG_PORT.printf(", ");
}

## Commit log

2020-03-09 CAM color sensor board
    [color_sensor_node.GBL, color_sensor_node.GBO, color_sensor_node.GBP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]
2020-03-09 add version number
    [color_sensor_node.brd]
2020-03-24 update packages, add rc filter to sensor vdd, move to smd connectors
    [color_sensor_node.brd, color_sensor_node.sch]
2020-03-24 simplify, remove mosfet
    [color_sensor_node.brd, color_sensor_node.sch]
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2020-03-25 clean up schematic
    [color_sensor_node.brd, color_sensor_node.sch]
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2020-05-29 hook designs
    [hook.brd]
2020-05-29 reformat sensor board for hook design
    [color_sensor_node.brd, color_sensor_node.sch]
2020-05-29 board designs
    [color_sensor_node.brd, sensor_node_backer.brd, sensor_node_inner_layer.brd]
2020-05-29 update color sensor node board for after dark colors
    [color_sensor_node.brd]
2020-05-29 add initial column controller schematic and board
    [column_controller.brd, column_controller.sch]
2020-06-09 miter column controller corners
    [column_controller.brd]
2020-06-09 bump column controller to v03
    [column_controller.brd, column_controller.sch]
2020-06-09 increase standoff size column controller
    [column_controller.brd, column_controller.sch]
2020-06-09 increase standoff size backer
    [sensor_node_backer.brd]
2020-06-09 increase standoff size sensor board
    [color_sensor_node.brd, color_sensor_node.sch]
2020-06-09 bump version sensor board
    [color_sensor_node.brd]
2020-06-09 increase standoff size mid board
    [sensor_node_inner_layer.brd]
2020-06-09 increase standoff size top board
    [sensor_node_top_layer.brd]
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2020-06-09 create BOM for electronic boards
    [bom_output.csv]
2020-06-21 add shield to inner board
    [sensor_node_inner_layer.brd]
2020-06-21 prepare for v10 generation
    [color_sensor_node.brd, color_sensor_node.sch, column_controller.brd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]
2020-06-21 update controller board
    [column_controller.brd, column_controller.sch]
2020-06-21 v10 CAM + Gerber Gen
    [color_sensor_node-Panel.GBL, color_sensor_node-Panel.GBO, color_sensor_node-Panel.GBP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]
2020-06-23 fixed overlapping milling lines in top layer
    [sensor_node_top_layer-Panel.brd, sensor_node_top_layer.brd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]
2020-06-23 increase width of shield
    [color_sensor_node.brd, sensor_node_backer.brd, sensor_node_top_layer.brd]
2020-07-09 correct structure for Arduino
    [conductor.ino, network_hub.ino]
2020-07-10 add staff debug print function
    clears the terminal and show the current state of the staff
2020-07-10 add communication between network_hub and conductor
    [configuration.h]
2020-07-10 mock up audio playback
    [configuration.h]
2020-07-11 add preliminary networking between hub and column controllers
    [configuration.h]
2020-07-11 switch to using onData
    onData seems to free up memory automatically, and is used in some examples online
2020-07-12 Added music player to playColumn()
    I added everything we'd need to get the correct note, instrument, and filename for each instance in the array, as well as the code that should play the filename. Still buggy though. It's completely silent, and I'm not sure why
    [conductor.ino]
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2020-07-13 add color detection
    [configuration.h]
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2020-07-13 allow user to set column
    press the "user" button to increment the column number
2020-07-15 add color address messages
    these messages from the conductor are used to set the color of the sensor node leds
2020-07-15 add frame and organize
    [column_controller.brd, column_controller.sch]
2020-07-15 Changed playbackPeriodDefault and updated conductor with a music player
    Changed playbackPeriodDefault to give the audio shield more time to play. I think it was getting out of sync too quickly with a shorter callback time.
    Conductor.ino now has a music player, still only gets data from the randomCart() function, but it plays it well when all the correct files are on the SD card
    [configuration.h]
2020-07-17 update sensor readings only on change
    - compare sensor values to locally stored value, send only if changed
    - ensure that sensor values are all transmitted upon startup
    [configuration.h]
2020-07-17 Added playbutton and bpm converter to conductor.ino
    Added an interrupt to handle the play/pause button, and a bpm converter function to take a value from the potentionmeter and convert it to microseconds
    [configuration.h]
2020-07-20 Changed bpm units
    Changed bpm units to make more sense, moved #define statements into the appropriate sketch
    [configuration.h]
2020-07-20 big effort
    - add double-buffered playback
    - add watchdog to audio
    - add rotary dial for BPM adjustment
    - add basic controls
    [configuration.h]
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2020-08-07 convert to WiFi mesh topology
    there is currently a bug where the sensor read method does not play nicely with the network tasks.... need to fix. But this is a good starting point
    [configuration.h]
2020-08-18 Revert "convert to WiFi mesh topology"
    This reverts commit 5ee60c3a18588d466c13f1dcdc843a4fe6a04865.
    [configuration.h]
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2020-08-18 rely on external network
    [configuration.h]
2020-08-27 got things working better
    still going to switch to a wired transport for the cat and cart messages
2020-09-28 attempt hacky I2C fix w/ sw changes
    [configuration.h]
2020-09-28 begin change to differential I2C solution
    [column_controller.brd, column_controller.sch]
2020-09-28 proto schematic for v11 column controller
    [column_controller.brd, column_controller.sch]
2020-09-28 add uart / i2c / column debug access headers
    [column_controller.brd, column_controller.sch]
2020-10-03 redesign + order column_controller board
    [column_controller-Panel.GBL, column_controller-Panel.GBO, column_controller-Panel.GBP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]
2020-10-24 remove 5V from AREF pin
    [column_controller.brd, column_controller.sch]
2020-10-25 switch to SAMD21 + i2c network architecture
    [configuration.h]
2021-03-23 change column controller back to esp32 w/ more leds
    [bom_output.csv, column_controller.brd, column_controller.sch]
2021-03-23 add prelim esp32 websocket code
    right now it appears to work poorly in production mode - however it still works. need to investigate further. operation locally in dev mode seems fine
2021-04-02 add rpi translation server
    this code will use the rpi to translate insecure websocket messages from the columns to secure websocket messages headed to the api server
    this is a workaround for the issue that the esp32 had using ssl to generate ```wss://``` messages
    [column_controller.ino, network.ino]
2021-04-08 fix incoming color order
    [utility.ino]
2021-04-08 add proper I2C pins for old generation hardware
    through some crazy circumstances we are going to be mostly using old hardware to control the columns
    this is the code to use the proper I2C pins
2021-04-08 bifurcate sensor led control apis
    this allows the desired led color to be set from interrupt contexts using 'setLed' or the '= CRGB' operator without calling FastLED.show(). doing so prevents some crashing
    the '_setIllumination' fn is used internally to immediately update the shown led color (but it does not store the color as the desired color, so it is possible to restore the led color later)
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2021-04-08 lock leds while reading sensors
    now that FastLED.show() is called during the reading time we need to prevent changes to the led color during the sampling period
2021-04-08 fix mistake with expected color format and color order to send to leds
    [utility.ino]
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2021-04-22 change purpose of conductor
    the conductor now acts as a USB keyboard that is informed by the large buttons of the rainbow forest. these keystrokes are sent to the web interface as commands.
    fix compile errors
    [conductor.ino, input.ino, keyboard.ino]
2021-05-03 clear colors when error occurs
    [network.ino, utility.ino]
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

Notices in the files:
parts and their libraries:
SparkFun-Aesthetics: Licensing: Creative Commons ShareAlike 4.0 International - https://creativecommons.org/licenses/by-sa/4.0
